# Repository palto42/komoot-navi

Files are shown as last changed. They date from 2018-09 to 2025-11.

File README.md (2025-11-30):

# BLE Receiver for Komoot naviagtion app

> ⚠️ **NOTE**: This repository has been archived and will not be updated anymore.

[Komoot](https://www.komoot.de) is a navigation app for Android and iPhone especially for cycling and hiking. The BLE protocoll for external navigation displays is described on [kommot/BLEConnect](https://github.com/komoot/BLEConnect)

This project implements a BLE receiver based on an ESP32 module and a 64*128 pixel OLED display to show the direction, distance and street name to the next junction.

The device is turned on via a touch input connected to the ESP32 pin 15 and automatically turns off if it doesn't receive new updates from the Komoot app for a while.

For more information, have a look at [Komoot BLE receiver description](/doc/Komoot%20BLE%20receiver.md).

## Navi in 3D-printed case

The name of the next street is shown at the top of the display. In the middle the direction and the distance to the next way point can be found. The bottom shows the current street name and below it the battery level.

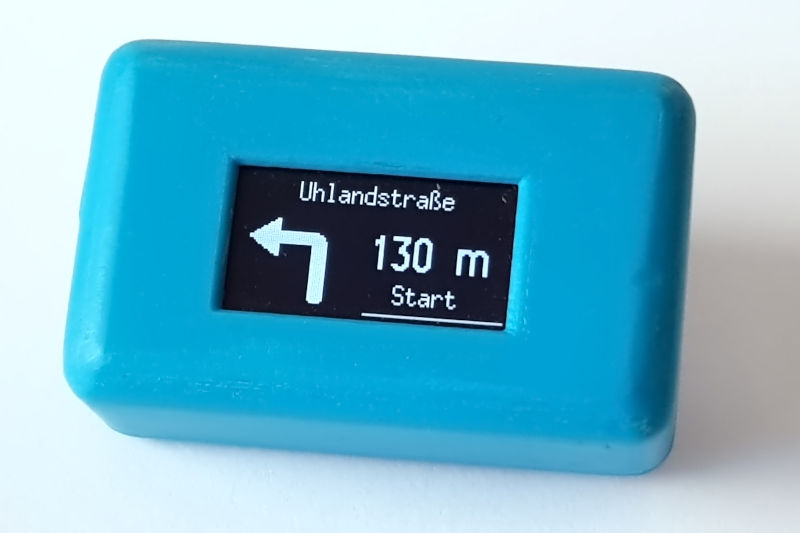
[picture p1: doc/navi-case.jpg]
navi in 3d-printed case


The Blender and STL files for the 3D-printed case are in the [/navi-case](/navi-case)] folder. It is designed for the Lolin32 lite and the 1.3" OLED display.

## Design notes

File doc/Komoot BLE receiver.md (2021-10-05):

# Komoot Navi Display

Small Bluetooth Low Enegergy (BLE) receiver to display the navigation information from the Komoot app (Android or iPhone).

## Function

The device is switched on by touching sensor pin 15 (default, can be changed in source code). It will show the battery voltage and then try to connect to the Komoot app (navigation in the app should be started befor turning on this BLE receiver). If it can't connect within 30 seconds, it will return to deep sleep.

If the device has connected to the Kommot app, it will show the directions to the next way point as also shown in the app.
At the top it will show the name of the next street. In the middle the direction and the distance to the next junction is shown. The bottom shows the current street name and below the battery voltage bar.

If the device doesn't receive updates from the app for more than 30 seconds (e.g. naviagtion finished or paused), it will turn off (enter deep spleep).

### Pairing the device with the Komoot app

Before using the device as Kommot navigation receiver, it needs to be paired with the Kommot app.
This is done in the app "Profile > Settings > Bluetooth Connect" (not via the system Bluetooth pairing).

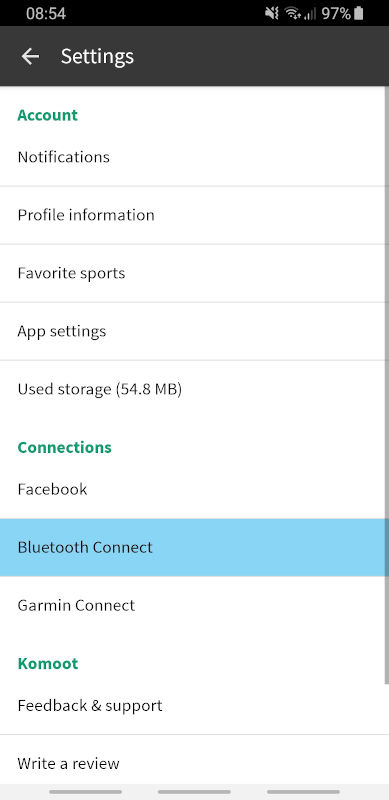
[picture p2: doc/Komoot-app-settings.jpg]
Komoot app settings


Then select "Ciclo HAC bike computer" from the "Connect anaother device" section and turn on the ESP32 navigation receiver.

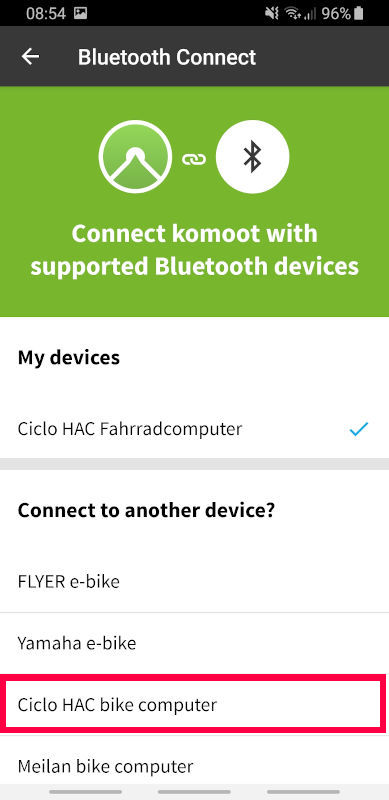
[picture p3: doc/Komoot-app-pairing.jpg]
Komoot device pairing


If the device was discovered ("Ciclo HAC Device &#10004;" shown above the "&#8634; Waiting for connection..."), you are done and need to manually go back to the settings.

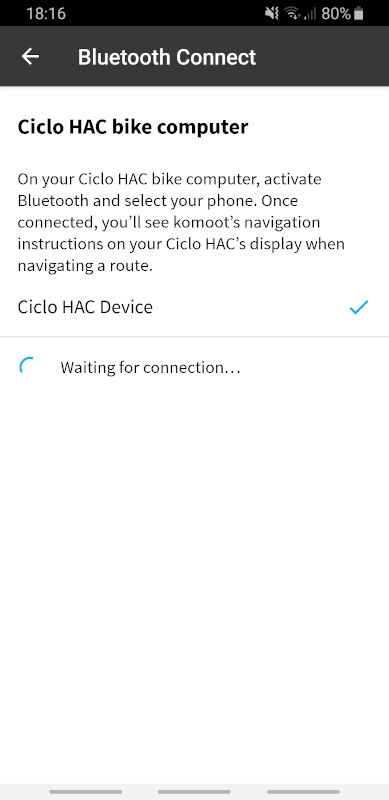
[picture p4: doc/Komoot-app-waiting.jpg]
Komoot device pairing


## Code

The code was originally developed with Arduino IDE, but then I changed to PlatformIO (on  VS Code or Atom editor) due to better integration with Git, faster code complilation and good dependency management for teh libraries.

The display orientation can be rotated by the value of the “rotation” variable in the code.

### Development

In PlatformIO the “Expressif 32” platform needs to be installed. The additional libraries “ESP32 BLE Arduino” for the Bluetooth Low Energy support and “U8g2” for the display driver are automatically loaded via the dependencies defined in the [platformio.ini](/platformio.ini) file.

The symbols have been converted and edited with Gimp to the required XBM format. For the navigation symbols I used the nav-icons provided in PNG format on the Komoot BLE Github [[1]](#References). The down-sizing required some manual corrections for smooth edges. I copied the xmb files in two C-libraries, one for the nav-icons and the second for some extra symbols.

## Circuit

The device was tested with a [Wemos Lolin32](https://wiki.wemos.cc/products:lolin32:lolin32) and the slightly smaller [Wemos Lolin32 lite](https://wiki.wemos.cc/products:lolin32:lolin32_lite), both can still be purchased on Ebay or similar. For the display an OLED 128x64 is used with either [0.96" (SSD1306 controller)](https://www.ebay.de/itm/0-96-I2C-IIC-Serial-128X64-128-64-White-OLED-LCD-LED-Display-Module-for-Arduino/122680684215) or [1.3" (SSD1106 controller)](https://www.ebay.de/itm/White-1-3-OLED-LCD-Display-Module-IIC-I2C-Interface-128x64-3-5V-For-Arduino/272827722582) size. The unit is powered with a 3.7 V LiPo battery.

A voltage devider with two resistors is used to measure the battery power. The battery level is shown with a bar indicator at the bottom of the display and the device turns off (deep sleep) if the power is too low.

Breadboard wiring:
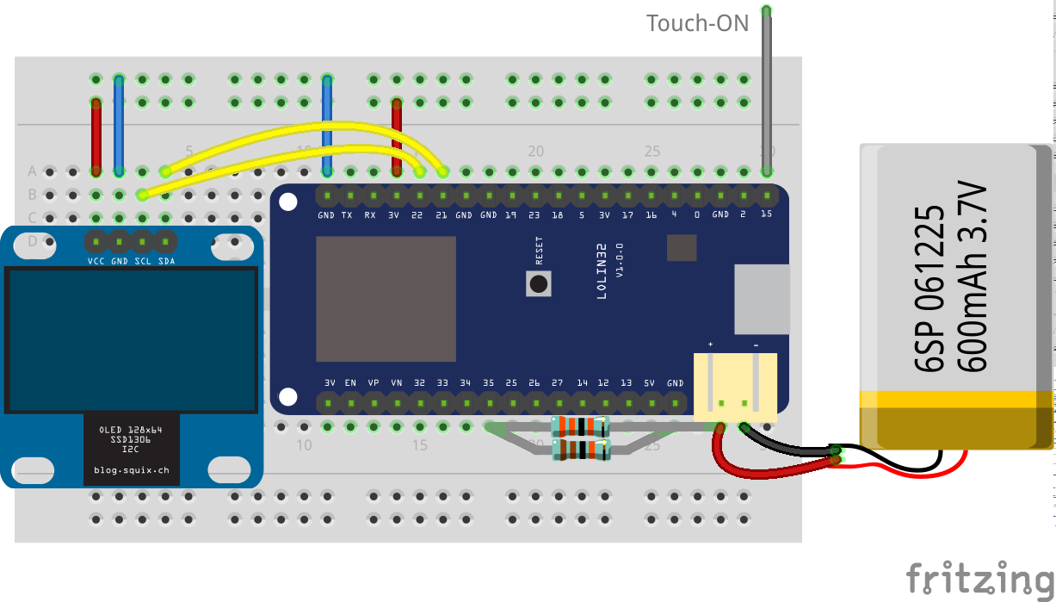
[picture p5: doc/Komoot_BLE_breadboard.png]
breadboard


Schematic:
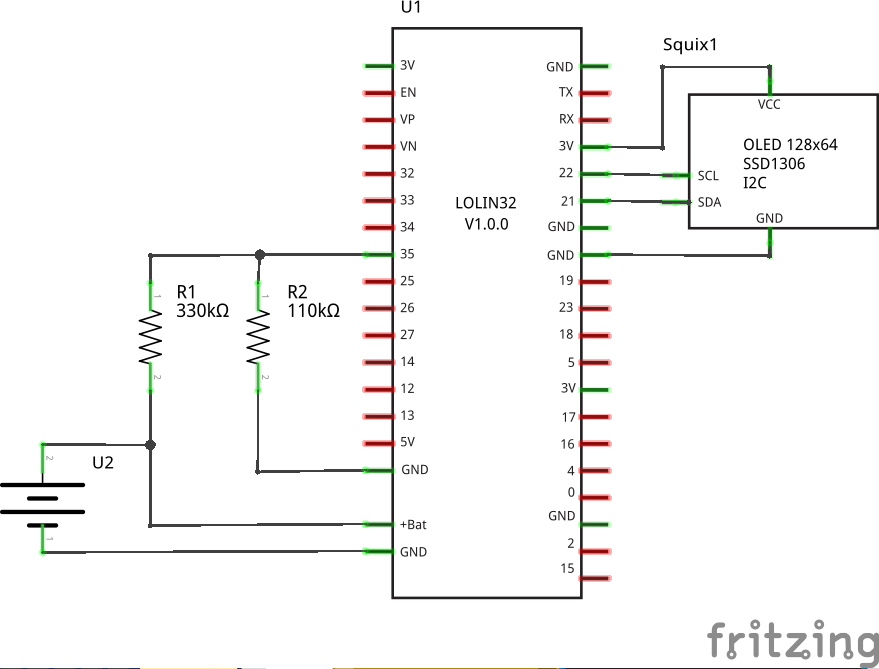
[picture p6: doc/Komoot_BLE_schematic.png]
schematic


The [Fritzing](https://fritzing.org) source file: [Komoot_BLE](Komoot_BLE.fzz)

### Components

* ESP32 board, e.g. LOLIN32 or Lolin32 lite (clones still available on Ebay)
* OLED display 128x64 with SH1106 or SSD1306 controller
* LiPo battery 3.7 V, 600 mAh

## References

1. Komoot BLE specification: [komoot/BLEConnect](https://github.com/komoot/BLEConnect)
2. PlatformIO [ESP32](http://docs.platformio.org/en/latest/platforms/espressif32.html)
3. Neil Kolban's [BLRexample file](https://github.com/nkolban/ESP32_BLE_Arduino)
4. Adreas Spiess Polar receiver [video #174](https://youtu.be/osneajf7Xkg)
5. Similar (newer) project [esp32_komoot_ble](https://github.com/jstiefel/esp32_komoot_ble)

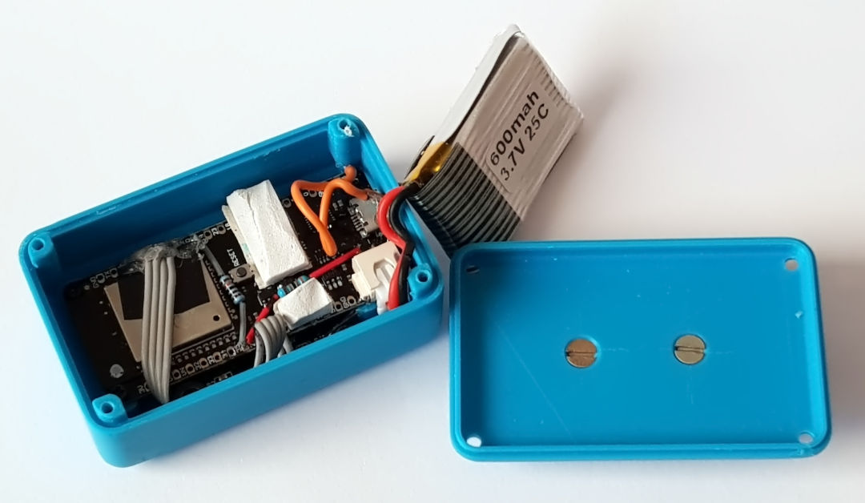
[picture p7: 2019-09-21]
doc/navi-case-open.jpg

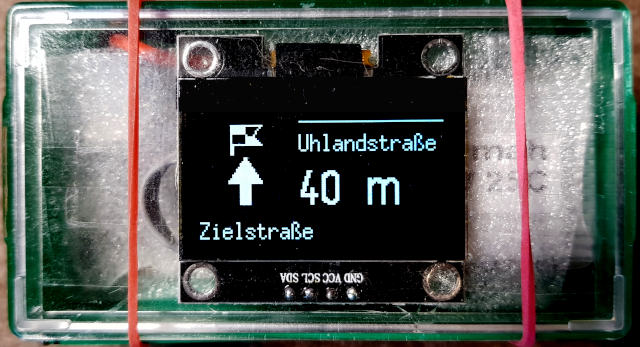
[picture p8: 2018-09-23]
doc/prototype.jpg

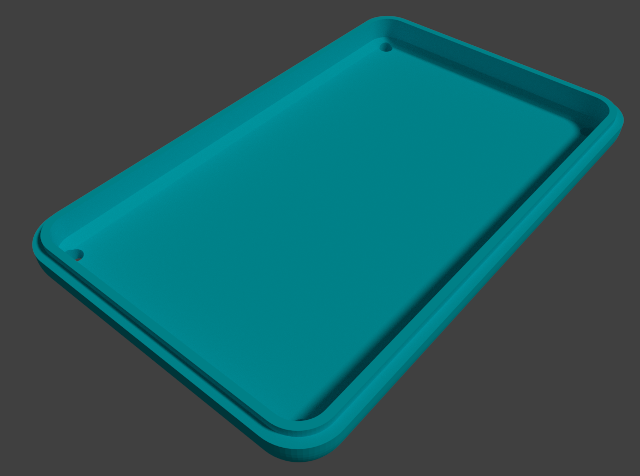
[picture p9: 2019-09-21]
navi-case/navi-case-cover.png

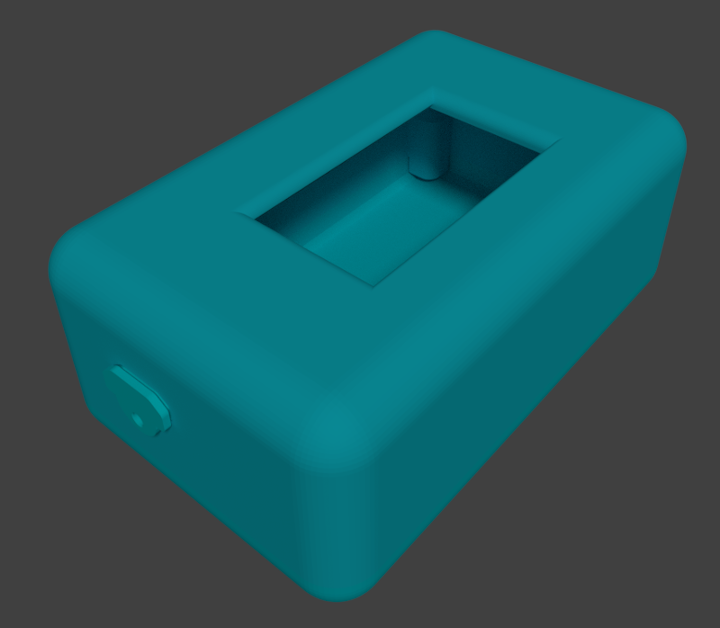
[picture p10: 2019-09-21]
navi-case/navi-case-view-top.png

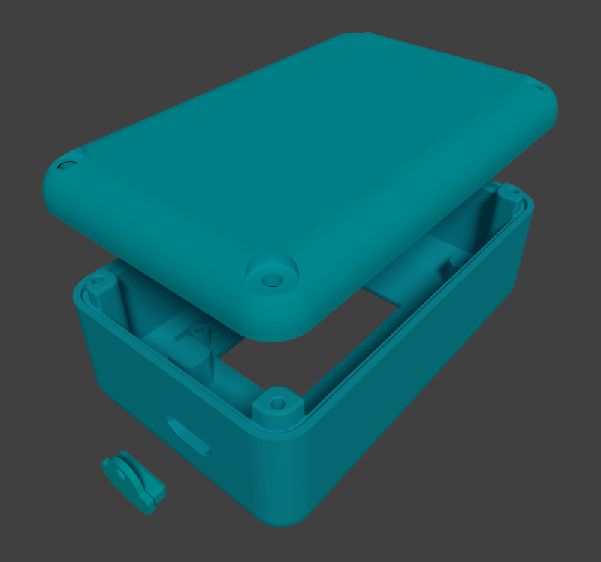
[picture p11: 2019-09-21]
navi-case/navi-case-view-bottom.png

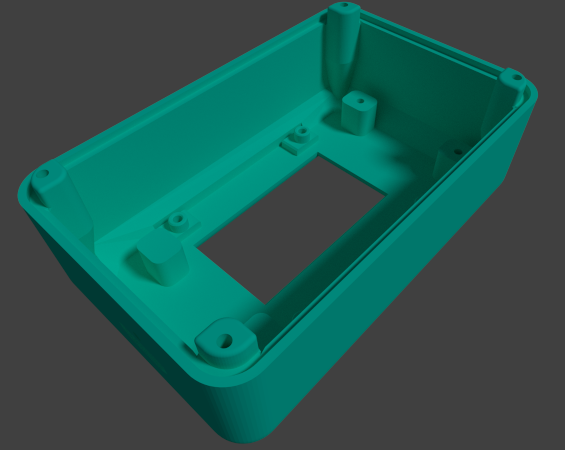
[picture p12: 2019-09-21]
navi-case/navi-case-bottom.png

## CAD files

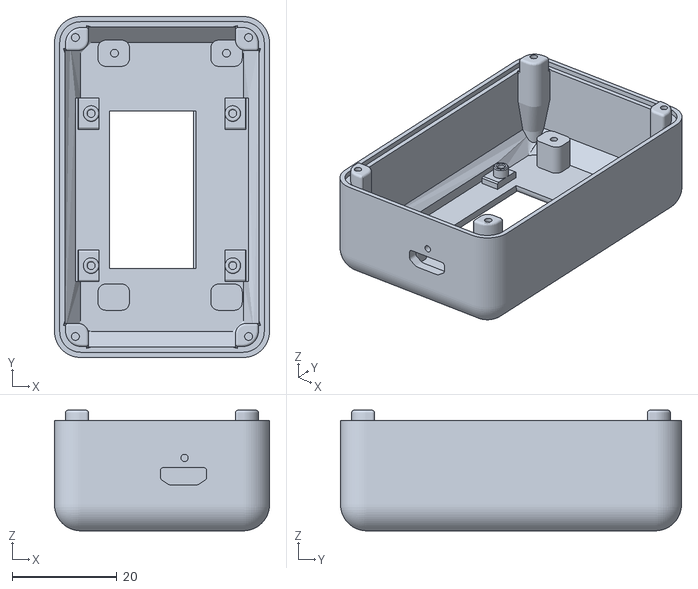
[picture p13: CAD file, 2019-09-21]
navi-case/navi-case-bottom.stl
41.0 x 65.0 x 23.0

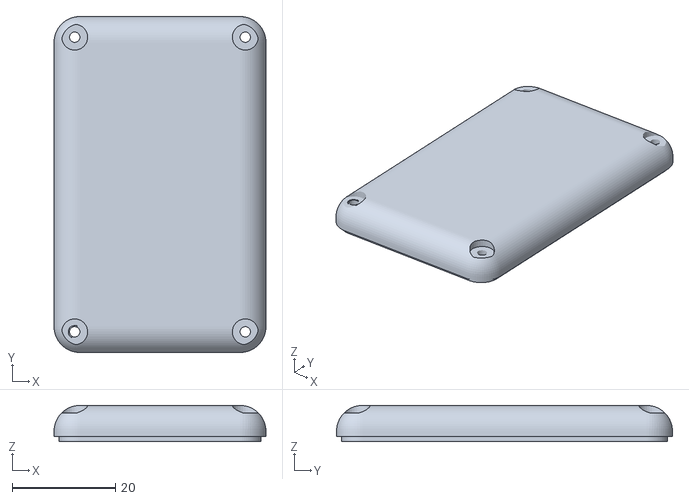
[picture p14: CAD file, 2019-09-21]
navi-case/navi-case-cover.stl
41.0 x 65.0 x 7.00

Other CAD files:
navi-case/LiPo_600mAh.blend
navi-case/lolin32.blend
navi-case/lolin32_lite.blend
navi-case/navi-case-bottom.blend
navi-case/navi-case-cover.blend
navi-case/navi-case-plug.blend
navi-case/oled.blend

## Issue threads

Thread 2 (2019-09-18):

Komoot Service not Discovered

thefriedc, 2019-09-18:
Hi @palto42,

thanks for sharing your project. I had the same idea with an ESP and display laying around at home. After some googling, I found your project.

I got a question according the BLE service scan and am hoping that you can help me out. I am having troubles discovering the Komoot service.

Also when using your code, the ESP32 does not find the Komoot BLE Service.
Komoot points out, that the ESP32 device must be paired with the Android device, but my Android phone cannot detect the ESP BLE client.

When I use the ESP BLE Server Sketch from Arduino IDE I can see the device in my Android Bluethooth devices list.

So my question: Did you need to pair your device in the Android settings and was there something you had to configure in the Komoot app for making this work?

I would be really grateful if you could point me in some direction.

Cheers Chris

palto42, 2019-09-20:
Hi @thefriedc
I'm using it with a Samsung S8 with Android 9 and latest Komoot version 10.2.6
There is no pairing required for this BLE service, you just need to start the navigation in Kommot and this will automatically start the BLE service. Then start the ESP and it should find the service and connect.
Just merged the Development branch into Master, but there was no change in the BLE code.
I'm using PlatformIO (under VS Code or Atom) for compiling with the BLE library is "ESP32 BLE Arduino" version >= 0.4.16 (as defined in the platformio.ini).

What environment have you used for compile/upload?

thefriedc, 2019-09-21:
Thanks a lot for the detailed information!

I am stuck with Android 8 on my Nexus 5x at the moment. I think this could cause the trouble.

Regarding the BLE Code - I tested with some BLE Tools and providing test services on my phone and I could detect all of them on my ESP. Nevertheless - I am not quite sure why Komoot pointed out the device pairing step explicitly on their github [README](https://github.com/komoot/BLEConnect)

Hopefully I can get an Android 9 device for testing soon.

Thanks for your help!
Chris

palto42, 2019-09-22:
Hi Chris

You are right that the device needs pairing, it was too long ago that I did it so that I forgot ;-)

But the pairing is not done in the Android Bluetooth settings but in the app itself. I updated the [README](https://github.com/palto42/komoot-navi/blob/develop/README.md) in the "develop" branch with short instructions.  Note that the device is paired as "Ciclo HAC bike computer".

I don't think that you need Android 9, I'm using this since more than a year ans as far as I remember it was still on Android 8 in the beginning.

thefriedc, 2019-09-22:
Thank you - I am getting a little bit closer. I can discover the service indeed, when komoot tries to find the "HAC bike computer" (how did you come up with that idea at all?)
Unfortunately - komoot is not able to discover the ESP client(?) so there is no pairing. Not getting past the "waiting for connection" message.

palto42, 2019-09-22:
The app stays in the connection dialog with "waiting for connection" even after it has discoveerd a device, but the discovered device is shown above the "waiting..." line.

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

If you see the "Ciclo HAC device" with a check mark, you have to manually go back to the settings.

Btw.: I found another similar project [jstiefel / esp32_komoot_ble ](https://github.com/jstiefel/esp32_komoot_ble).

thefriedc, 2019-09-22:
I am never getting a checkmark during the connection process...

Actually I found out that there is maybe some Problem with the ESP32 BLE lib which is actually Version 1.0.1 now. My ESP is rebooting upon a kernel panic after reading the ble characteristic

I also found the other project already - there is also someone who also encountered the kernel panic problem  :) https://github.com/jstiefel/esp32_komoot_ble/issues/3#issuecomment-530089381

Thanks again for putting in such an effort!

Just in case - I'll let you know, when I made some progress.

palto42, 2019-09-23:
Thanks for the hint regarding issues with new version, although I'm not sure if it's a bug in the BLE library or the Espressif ESP32 platform code 1.10.0 (or the combination).

First I tried my current code with old BLE lib 0.4.16 and new 1.0.1. Both didn't connect to Komoot, but I also didn't face kernel panic. It was just got stuck in the connection process.

Then I checked the updated examples on [ESP32_BLE_Arduino](/nkolban/ESP32_BLE_Arduino) and copied the changes to my code in new branch [testing](/palto42/komoot-navi/tree/testing). With this the connection in the Komoot app settings can be established, but now I get the kernel panic if it tries to connect in navigation mode.

... so this needs some more testing and debugging

thefriedc, 2019-09-23:
Never touch a running systen ;)

Sorry, to have you put in this situation. Everything seemed to work just fine.

So I also tried your code from testing branch.
According to serial output the service is discovered and characteristics is obtained but then it seems to be stuck as you described:

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

But I still do get the kernel panic after some time - say 25 seconds.

Did you try to disconnect your device and start the initial connection process over?

palto42, 2019-09-24:
No worries, I still have my working device and try the new code on different test setup :-)

I can disconnect/re-connect the device old working code without issues, only with the current code doesn't work and gets stuck in panic loop.

thefriedc, 2019-09-24:
Just to make sure: the panic loop is already during the connection screen
on komoot?

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

palto42, 2019-09-24:
The panic loop starts if I start the navigation in the app. No crash if I just do the initial pairing (seems most other devices also work for pairing, e.g. 'Metz')

It always crashes in the "connectToServer" function after "Refernce to characteristics obtained" if it tries to register for notifications `pRemoteCharacteristic->registerForNotify(notifyCallback);`.

```
...
connectToServer:  - Create client
 - Connected to server
 - Refernce to service obtained - Refernce to characteristics obtained
 - can read
The characteristic value was: 9'#<␂�
 - can notify
```
Added some extra print commands for debugging this in testing branch.

palto42, 2019-09-24:
I tried the proposed fix from https://github.com/nkolban/esp32-snippets/issues/902#issuecomment-529969098 and it seems to work.

I created fored the BLE lib and applied the fix in testing branch: https://github.com/palto42/ESP32_BLE_Arduino.git#testing (in PlatformIO I can simply reference this as library dependency).

No other code changed than https://github.com/nkolban/esp32-snippets/blob/master/cpp_utils/BLERemoteCharacteristic.cpp#L465-L466

thefriedc, 2019-09-24:
Now I am completely lost. Didn't the instruction of chegewara mean to "remove" those two lines? Not to add them?

Nevertheless - I switched to PlatformIO on VS Code (Used Arduino IDE before) and also included your modified fork of BLE Arduino as dependency. Thanks for the hint!
My Komoot app is still stuck on during the device connection process. There is never a device showing up in my Komoot app.

The serial output of my ESP would look promising

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

But I am still missing the

> Connected to desired service on BLE server

Seems my system is still stuck on the
`pRemoteCharacteristic->registerForNotify(notifyCallback);

I switch to your master branch and try my luck there ...

thefriedc, 2019-09-25:
Today, I tried to connect with an Android 9 phone it worked right away! Connected instantly and navigation instructions were written to the serial monitor when a route was started.
Display does not show anything but this is OK since I am using a different display.

Komoot Version is 10.2.6 (using the same on my Android 8.1) Used the code of your testing branch and the BLE lib fork.

Thank you very much again for helping and sharing this cool project!

One question left: How long can you run your BLE thingy with an LiPo 600mAh battery?

palto42, 2019-09-26:
I have not really tested the operation time of the 600mAh LiPo, but I think it's maybe a bit oversized. I mainly selected it because it was cheap and size was ok.
I have a smaller 150mAh LiPo which I will try next.

glatteis, 2020-03-03:
Hi, I have the same issue but I don't see the kernel panic.
All I get is
`Offset info: 60, distance: 58, dist width: 62
Dist max length: 7
Info max length: 11
Show messge: BLE try to connect
Scan time: 0`

glatteis, 2020-03-03:
Hi, I still have a panic on the testing branch with the testing library:
`Show messge: BLE try to connect
BLE Advertised Device found: Name: Samsung Galaxy A5 2017, Address: 60:05:d6:e6:6f:b6, serviceUUID: 71c1e128-d92f-4fa8-a2b2-0f171db3436c
Scan time: 0
connectToServer:  - Create client
 - Connected to server
 - Refernce to service obtained - Refernce to characteristics obtained
 - can read
The characteristic value was:
 - can notify
Guru Meditation Error: Core  1 panic'ed (LoadProhibited). Exception was unhandled.
Core 1 register dump:
PC      : 0x401801b3  PS      : 0x00060330  A0      : 0x800d6953  A1      : 0x3ffcb660
A2      : 0x00000000  A3      : 0x3ffe0830  A4      : 0x00000024  A5      : 0x00000024
A6      : 0x000000b6  A7      : 0x6669746f  A8      : 0x80170178  A9      : 0x3ffcb610
A10     : 0x3ffe0830  A11     : 0x40085a38  A12     : 0x0000001c  A13     : 0x3ffe0854
A14     : 0x00ff0000  A15     : 0xff000000  SAR     : 0x00000018  EXCCAUSE: 0x0000001c
EXCVADDR: 0x00000030  LBEG    : 0x4000c2e0  LEND    : 0x4000c2f6  LCOUNT  : 0x00000000

Backtrace: 0x401801b3:0x3ffcb660 0x400d6950:0x3ffcb680 0x400d6041:0x3ffcb6b0 0x400d2791:0x3ffcb700 0x400d31e8:0x3ffcb770 0x400dc5a9:0x3ffcb870 0x4008f1c5:0x3ffcb890

Rebooting...`

glatteis, 2020-03-03:
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

Same for me for getting stuck at registerForNotify. Did it work on every version of Android that you tried? My phone has Android 7, beginning to suspect that may be the cause...

thefriedc, 2020-03-03:
> Same for me for getting stuck at registerForNotify. Did it work on every version of Android that you tried? My phone has Android 7, beginning to suspect that may be the cause...

Well, it did never work on stock Android. Tested versions are 8 and 9 (stock and Android One).

I could make it work on a Huawei device with their Android 9. And it worked on a Samsung Galaxy 6 device with (I guess) Android 8.

I wonder if one of those proprietary bike computer devices which use BLE connect can connect with Komoot running on native Android.

I cannot find that Komoot BLE github repo anymore. Did they remove it?

palto42, 2020-03-04:
Komoot moved the documentation from Github to Google Docs https://docs.google.com/document/d/1iYgV4lDKG8LdCuYwzTXpt3FLO_kaoJGGWzai8yehv6g/

thefriedc, 2020-03-04:
Yes, I recognized that. I guess, this was done so no one can post bugs to
their repository anymore.

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

Closed 2019-09-25.

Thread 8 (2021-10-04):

Problems connecting to the app even though the service gets detected

adam2809, 2021-10-04:
I am trying to install this project on my TTGO Lora32 V2 and my device seems to detect the BLE service (It displays the service uuid in the attached log file line 48, tries to connect in line 57) but always fails to connect to it without giving an error I tried using the BLE ESP32 Arduino library downloaded from both from pio in lib _deps and the version disccussed here https://github.com/palto42/komoot-navi/issues/2 that is this repo: https://github.com/palto42/ESP32_BLE_Arduino.git#testing. Does anybody have an idea what might be happening?

PS

I couldn't get the Serial.print to show up but logs worked fine so I am submitting a PR with Serial.println replaced with ESP_LOG which makes it a bit more readable

[failed_connection_attempt.log](https://github.com/palto42/komoot-navi/files/7280917/failed_connection_attempt.log)

palto42, 2021-10-05:
Hi @adam2809 , thanks for your interest in my app.
I haven't worked on it since 2 years anymore since it worked for me and I finally rarely used it.
I have re-compiled it with latest VScode, PlatformIO and libraries and confirm that I see the same issues on a device which worked with old build. So it's most likely not a hardware issue but something changed on the libraries or ESP platform.

Not sure if I will have time for troubleshooting in the near future, but happy to try and suggestions or PR from you.

I tested your PR in new branch `esp_log` and looks good.

adam2809, 2021-10-05:
I'll give it a look but also I'm considering rewriting this in esp-idf since it tends to be more reliable in my experience. Also would you mind adding a hacktoberfest-accepted label on my PR? I'm looking to get a free t-shirt :  )

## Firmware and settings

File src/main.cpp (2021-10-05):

/*
 * BLE receiver for Komoot navi app
 * The Komoot BLE communication is described on https://github.com/komoot/BLEConnect
 *
 * This sketch was inspired by code from <Andreas Spiess>
 * https://github.com/SensorsIot/Bluetooth-BLE-on-Arduino-IDE/blob/master/Polar_Receiver/Polar_Receiver.ino
 * which is based on Neil Kolban's example file: https://github.com/nkolban/ESP32_BLE_Arduino

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
  THE SOFTWARE IS PROVIDED "AS IS", WITHOUT WARRANTY OF ANY KIND, EXPRESS OR IMPLIED, INCLUDING BUT NOT LIMITED TO THE WARRANTIES OF MERCHANTABILITY,
  FITNESS FOR A PARTICULAR PURPOSE AND NONINFRINGEMENT. IN NO EVENT SHALL THE AUTHORS OR COPYRIGHT HOLDERS BE LIABLE FOR ANY CLAIM, DAMAGES OR OTHER
  LIABILITY, WHETHER IN AN ACTION OF CONTRACT, TORT OR OTHERWISE, ARISING FROM, OUT OF OR IN CONNECTION WITH THE SOFTWARE OR THE USE OR OTHER
  DEALINGS IN THE SOFTWARE.
 */

#define DEBUG 0 // flag to turn on/off debugging

#include <Arduino.h>
#define Serial if(DEBUG)Serial

#include <string>

#include "BLEDevice.h"
#include "soc/rtc.h"

#include<U8g2lib.h>
#include<Wire.h>
#include "esp_log.h"
#define tag "main"

#define Threshold 75 /* touch pin threshold, greater the value = more the sensitivity */

#define PIN_SCL 22
#define PIN_SDA 21

// U8g2 Contructor
// see https://github.com/olikraus/u8g2/wiki/u8g2setupcpp
// The hardware I2C allows pin remapping for some controller types. The optional
// pin numbers are listed after the reset pin: ..._HW_I2C([reset [, clock, data]]).
// Use U8X8_PIN_NONE if the reset input of the display is not connected.
#if DEBUG
// using small OLED on dev-platform
//U8G2_SSD1306_128X64_NONAME_F_HW_I2C u8g2(U8G2_R0, /* reset=*/ U8X8_PIN_NONE, /* clock=*/ PIN_SCL, /* data=*/ PIN_SDA );   // 0.8" OLED
U8G2_SSD1306_128X64_NONAME_F_HW_I2C u8g2(U8G2_R0, /* reset=*/ U8X8_PIN_NONE, /* clock=*/ PIN_SCL, /* data=*/ PIN_SDA);   // ESP32 HW I2C with pin remapping
#else
U8G2_SH1106_128X64_NONAME_F_HW_I2C u8g2(U8G2_R0, /* reset=*/ U8X8_PIN_NONE);   // 1.3" OLED
//U8G2_SH1106_128X64_NONAME_F_HW_I2C u8g2(U8G2_R0, /* reset=*/ U8X8_PIN_NONE, /* clock=*/ PIN_SCL, /* data=*/ PIN_SDA);   // remapping I2C pins
#endif

const int rotation = 1;  // display rotaion: 0=none, 1=180deg

// local library with navigation icons and extra symbols
#include <symbols.h>

// Komoot Connect service and characteristics
static BLEUUID serviceUUID("71C1E128-D92F-4FA8-A2B2-0F171DB3436C"); // navigationServiceUUID
static BLEUUID charUUID("503DD605-9BCB-4F6E-B235-270A57483026");    // navigationServiceNotifyCharacteristicUUI
static BLEUUID heartUUID("6D75DBF0-D763-4147-942A-D97B1BC700CF");   // navigationServiceHeartbeatWriteCharacteristicUUID

static BLEAddress *pServerAddress;
static BLERemoteCharacteristic* pRemoteCharacteristic;
static boolean doConnect = false;
static boolean connected = false;

boolean new_notify = false;
boolean new_street = false;
int heartbeat = 0;
int timeout = 0;
int scan_time = 0;
uint8_t old_data[20];
std::string value = "Start";

const int battPin = 35; // A2=2 A6=34
unsigned int raw=0;
float volt=0.0;
// ESP32 ADV is a bit non-linear
const float vScale1 = 225.0; // divider for higher voltage range
const float vScale2 = 245.0; // divider for lower voltage range

std::string street = "Start";
std::string street_old = "";

void callback(){
  //placeholder callback function for touch
  ESP_LOGI(tag,"Touch!");
}

static void notifyCallback(
  BLERemoteCharacteristic* pBLERemoteCharacteristic,
  uint8_t* pData,
  size_t length,
  bool isNotify) {
    timeout = 0;
    // pData 4 = direction, 5-8 = distance, 9.. street
    // check if direction has changed
    if (pData[4] != old_data[4]) {
      new_notify = true;
      new_street = true;
      memcpy(old_data,pData,20);
    } else { // check if street has changed
      for (int i = 9; i < 20; i++) {  // 4 = direction, 5-8 = distance, 9.. street
        if (pData[i] != old_data[i]) {
          new_notify = true;
          new_street = true;
          memcpy(old_data,pData,20);
          break;
        }
      }
    }
    if (! new_street) { // checkj if distance has changed
      for (int i = 5; i < 9; i++) {
        if (pData[i] != old_data[i]) {
          new_notify = true;
          memcpy(old_data,pData,20);
          break;
        }
      }
    }
    ESP_LOGD(tag,"Receiving notification");
}

std::string utf8_substr(const std::string& str, unsigned int start, unsigned int leng)
{
    if (leng==0) { return ""; }
    unsigned int c, i, ix, q, min=std::string::npos, max=std::string::npos;
    for (q=0, i=0, ix=str.length(); i < ix; i++, q++)
    {
        if (q==start){ min=i; }
        if (q<=start+leng || leng==std::string::npos){ max=i; }

        c = (unsigned char) str[i];
        if      (
                 //c>=0   &&
                 c<=127) i+=0;
        else if ((c & 0xE0) == 0xC0) i+=1;
        else if ((c & 0xF0) == 0xE0) i+=2;
        else if ((c & 0xF8) == 0xF0) i+=3;
        //else if (($c & 0xFC) == 0xF8) i+=4; // 111110bb //byte 5, unnecessary in 4 byte UTF-8
        //else if (($c & 0xFE) == 0xFC) i+=5; // 1111110b //byte 6, unnecessary in 4 byte UTF-8
        else return "";//invalid utf8
    }
    if (q<=start+leng || leng==std::string::npos){ max=i; }
    if (min==std::string::npos || max==std::string::npos) { return ""; }
    return str.substr(min,max);
}

void show_message(std::string header, int sym_num = 32, std::string distance="Komoot",
                  std::string info="Navigation", float volt=0) {
  // Show message and symbol (max size = 64 w * 48 h)
  const int max_header = 128 / 6;
  header = utf8_substr(header,0,max_header);
  int icon_width = std::max(52,symbols[sym_num].width);
  int x_offset = std::max(0,24 - symbols[sym_num].width / 2);
  int y_offset = 40 - symbols[sym_num].height / 2;
  ESP_LOGD(tag,"Icon x-offset: %d , y-offset: %d",x_offset,y_offset);
  // need to set font before getting the message width
  u8g2.setFont(u8g2_font_6x13_te);
  int header_pos_x = std::max(0,63 - u8g2.getUTF8Width(header.c_str()) / 2);
  int info_pos_x = icon_width + std::max(0,(127 - icon_width - u8g2.getUTF8Width(info.c_str())) / 2);
  ESP_LOGD(tag,"Header length: %d width: %d, offset: %d",header.length(),u8g2.getUTF8Width(distance.c_str()),header_pos_x);
  u8g2.setFont(u8g2_font_logisoso16_tr);  // width 10, heigth 16
  int dist_pos_x = icon_width + std::max(0,(127 - icon_width - u8g2.getUTF8Width(distance.c_str())) / 2);
  ESP_LOGD(tag,"Offset info: %d , distance: %d, dist width: %d",info_pos_x,dist_pos_x,u8g2.getUTF8Width(distance.c_str()));
  int max_dist = (128 - dist_pos_x) / 10;
  distance = utf8_substr(distance,0,max_dist);
  ESP_LOGD(tag,"Dist max length: %d",max_dist);
  int max_info = (128 - info_pos_x) / 6;
  info = utf8_substr(info,0,max_info);
  ESP_LOGD(tag,"Info max length: %d",max_info);
  // use full buffer mode
  u8g2.clearBuffer();
  u8g2.drawXBMP(x_offset,y_offset,
                symbols[sym_num].width, symbols[sym_num].height,
                symbols[sym_num].xmp_bitmap);
  u8g2.setFont(u8g2_font_logisoso16_tr);
  //dist_pos_x = 52;
  u8g2.setCursor(dist_pos_x, 42);
  u8g2.print(distance.c_str());
  u8g2.setFont(u8g2_font_6x13_te);
  //header_pos_x = 0;
  u8g2.setCursor(header_pos_x, 12);
  u8g2.print(header.c_str());
  // show extra info (e.g. current street)
  u8g2.setFont(u8g2_font_6x13_te);
  //info_pos_x = 52;
  u8g2.setCursor(info_pos_x, 58);
  u8g2.print(info.c_str());
  // show battery voltage
  // draw a line from X=52 to x=127 for full battery (75 px)
  // Vmin = 3.0 Vmax=4.2 (delta 1.2)
  int batt_length = int((volt - 3.0) / 1.2 * 75);
  batt_length = _min (batt_length,75);
  u8g2.drawHLine(126-batt_length,63,batt_length);
  u8g2.sendBuffer();  // full buffer mode
  ESP_LOGI(tag,"Show messge: %s",header.c_str());
}

bool connectToServer(BLEAddress pAddress) {
  BLEClient* pClient  = BLEDevice::createClient(); // or use global pClient ?
  // Connect to the remove BLE Server.
  pClient->connect(pAddress);
  // Obtain a reference to the service we are after in the remote BLE server.
  BLERemoteService* pRemoteService = pClient->getService(serviceUUID);
  if (pRemoteService == nullptr) {
    return false;
  }
  // Obtain a reference to the characteristic in the service of the remote BLE server.
  pRemoteCharacteristic = pRemoteService->getCharacteristic(charUUID);
  if (pRemoteCharacteristic == nullptr) {
    return false;
  }
  // Read the value of the characteristic.
  std::string value = pRemoteCharacteristic->readValue();
  pRemoteCharacteristic->registerForNotify(notifyCallback);
  // Display that BLE has been connected
  show_message("BLE connected",34);
  ESP_LOGI(tag,"Connected to desired service on BLE server");
  return true;
}

// Scan for BLE servers and find the first one that advertises the service we are looking for.
class MyAdvertisedDeviceCallbacks: public BLEAdvertisedDeviceCallbacks {
    //Called for each advertising BLE server.
    void onResult(BLEAdvertisedDevice advertisedDevice) {
      // We have found a device, let us now see if it contains the service we are looking for.
      if (advertisedDevice.haveServiceUUID() && advertisedDevice.getServiceUUID().equals(serviceUUID)) {
        advertisedDevice.getScan()->stop();
        pServerAddress = new BLEAddress(advertisedDevice.getAddress());
        doConnect = true;
      } // Found our server
    } // onResult
}; // MyAdvertisedDeviceCallbacks

// Main program setup
void setup() {
  Serial.begin(115200);
  ESP_LOGI(tag,"Starting Arduino BLE Client application...");

  // reduce clock speed to save power
  // supported values = 2M (no BLE), 80M, 120M, 240M
  rtc_cpu_freq_config_t freq_conf;
  rtc_clk_cpu_freq_to_config(RTC_CPU_FREQ_80M, &freq_conf);
  rtc_clk_cpu_freq_set_config(&freq_conf);

  touchAttachInterrupt(T3, callback, Threshold); // Touch 3 = GPIO 15
  esp_sleep_enable_touchpad_wakeup();

  pinMode(battPin, INPUT);
  raw  = analogRead(battPin);
  volt = raw / vScale1;
  ESP_LOGI(tag,"Battery = %d",volt);

  u8g2.begin();
  u8g2.setFlipMode(rotation);
  // enable UTF8 support for the Arduino print() function
  u8g2.enableUTF8Print();
  u8g2.setFontDirection(0);

  if (volt < 3.2) { //sleep below 3.2 V
    show_message("Switching off now...",36,"LOW","battery",volt);
    delay(999);
    u8g2.setPowerSave(1);
    //esp_wifi_stop();
    esp_deep_sleep_start();
  }

  // Welcome screen
  show_message("©2018 Matthias Homann"); // developer
  delay(500);
  String v_str = "Akku: " + String(volt,1) + "V";
  show_message(v_str.c_str()); // battery status
  delay(500);

  BLEDevice::init("");

  // Retrieve a Scanner and set the callback we want to use to be informed when we
  // have detected a new device.  Specify that we want active scanning and start the
  // scan to run for 30 seconds.
  BLEScan* pBLEScan = BLEDevice::getScan();
  pBLEScan->setAdvertisedDeviceCallbacks(new MyAdvertisedDeviceCallbacks());
  pBLEScan->setActiveScan(true);

  // show BLS status "try to connect"
  show_message("BLE try to connect",33);

  uint32_t scan_time = millis();
  pBLEScan->start(30); // try 30s to find a device
  scan_time = millis() -scan_time;
  ESP_LOGI(tag,"Scan time: %d",scan_time/1000);
  if (scan_time > 29000) {
    // timeout
    show_message("No BLE, will turn off",35);
    delay(999); // 3s delay, 1000/3 for clock 80M=240M/3
    //ESP.restart();
    u8g2.setPowerSave(1);
    //esp_wifi_stop();
    esp_deep_sleep_start();
  }
} // End of setup.

// Main program loop
void loop() {
  // If the flag "doConnect" is true then we have scanned for and found the desired
  // BLE Server with which we wish to connect.  Now we connect to it.  Once we are
  // connected we set the connected flag to be true.
  if (doConnect == true) {
    if (connectToServer(*pServerAddress)) {
      connected = true;
    } else {
      connected = false;
    }
    doConnect = false;
  }
  // poweroff if timeout exceeded
  if (timeout > 30) {
     // show BLS status "disconnected"
      show_message("BLE disconnected",36);
      connected = false;
      delay(999); // 3s delay, 1000/3 for clock 80M=240M/3
      //ESP.restart();
      u8g2.setPowerSave(1);
      //esp_wifi_stop();
      esp_deep_sleep_start();
  }

  if (new_notify || heartbeat > 4) {  // refresh at least every 4 seconds
    new_notify = false;
    if (new_street || heartbeat > 4) {  // get full new street, at least every 4 seconds (to keep BLE connection)
      heartbeat = 0;
      // Read the latest value of the characteristic.
      value = pRemoteCharacteristic->readValue();
      if (new_street) {
        new_street = false;
        street_old = street;
        street = value.substr(9);
        ESP_LOGI(tag,"Street: %s",street.c_str());
      }
    }
    // calculate the distance to next fork
    // ignore 4th Byte, assume distance is below 16777 km ;-)
    double dist = int(old_data[5])+int(old_data[6])*256+int(old_data[7])*65536;
    int digits = 0;
    std::string dist_unit = " m";
    if (dist > 1000) { // km unit
      dist = dist / 1000;
      dist_unit = " km";
      if (dist < 2000) { // show 100m steps
        digits = 1;
      }
    } else {  // m unit
      if (dist > 200) { // 50 m steps
        dist = int(dist / 50) * 50;  // round down
      } else // 10m steps
        dist = int(dist / 10) * 10;  // round down
    }
    dist_unit = String(dist,digits).c_str() + dist_unit;
    ESP_LOGI(tag,"Distance: %d",dist);
    // std::string street = value.substr(9);
    // get battery voltage
    raw  = analogRead(battPin);
    volt = raw / vScale2;
    if (volt < 3.1) { //sleep below 3.1 V
      show_message("Switching off now...",36,"LOW","battery",volt);
      delay(999);
      u8g2.setPowerSave(1);
      //esp_wifi_stop();
      esp_deep_sleep_start();
    }

    show_message(street.c_str(),old_data[4],dist_unit,street_old.c_str(),volt);

    u8g2.setFont(u8g2_font_6x13_te);
    int text_offset = 64 - u8g2.getUTF8Width(street.c_str()) / 2;
    text_offset = std::max(0, text_offset);
    u8g2.firstPage();
  }
  timeout++;
  heartbeat++;
  delay(333); // 1s delay, 1000/3 for clock 80M=240M/3
} // End of loop

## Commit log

2018-09-23 inital release
    [Komoot_BLE.fzz]
2018-09-23 .gitignore update
    [Komoot_BLE.fzz]
2018-09-23 doc updates
    [Komoot_BLE.fzz]
2018-09-25 fixed pairing issue / connection timeout
    [main.cpp]
2018-09-27 add low battery symbol
2018-09-30 U8G2 set I2C pins and full buffer mode
2019-09-21 3D-printed case
    [LiPo_600mAh.blend, lolin32.blend, lolin32_lite.blend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]
2019-09-22 Update readme with device pairing
2021-10-04 Replaces Serial.prints with logger
    [main.cpp]
